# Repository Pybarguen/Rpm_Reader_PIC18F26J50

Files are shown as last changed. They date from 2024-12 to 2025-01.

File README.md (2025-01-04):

# **RPM Reader Using Encoder Sensor and PIC18F26J50**

Photography

**The objetive of this project is to change the speed of a motor using the PWM and read the RPM using a sensor encoder**

Download the files a create a new project on **MPLAB IDE**.

## Materials List

* 1 -PIC18F26J50
* 1- ST7735 128X160 TFT Dispplay
* 1- F249 Speed sensor module
* 1- FF030 DC Motor 3V - 6V
* 1- AMS1117 3.3 Voltaje regulator
* 1- Button N.O
* 1- Mosfet IRF634A
* 1- 2N3904 or 2N2222 Transistor
* 1- PC817 optocoupler
* 1- Pickit2 or recent version
* 2- capacitor 10uF
* 2- 1N4004 diode
* 2- 220 Ohm Resistor
* 3- 10K Ohm Resistor

## **Programs List**
* MPLAB IDE
* Pickit 2 or recent version
* KICAD
* Proteus (Optional)
* Blender

**PIC18F2xJ50** Needs a basic circuit connection for work, you can make a fast circuit on your protoboard using **28-pin SOIC DIP adapter** or you can make the PCB circuit :
**Make sure that you have read the PIC18F2xJ0 this device can be obtain in diferents packages 28-Pin SPDIP/SOIC/SSOP** get the correct adapter for you device

Soic_Adapter

you can get **28-pin SOIC DIP adapter** on this link :

https://www.robotshop.com/es/products/adaptador-sparkfun-soic-a-dip-28-pin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

https://es.aliexpress.com/w/wholesale-SOIC-28-adapter.html?spm=a2g0o.productlist.search.0

## **PIC18F26J50 Lite Develoment Board**

This is a basic PCB board for test faster your prototypes using PIC18F26J50 microcontroller, **you can use it on your protoboard** I'm working in a advance version you could see it in others repositories, you can find lite_version'files on this project.

3DCircuit

**IF You can get this board in PCBWAY**
click here

<a href="https://www.pcbway.com/project/shareproject/PIC16F26J50_Lite_Develoment_Board_c47685f1.html">PCB from PCBWay</a>

**Updating More Information about this setion**

## **Encoder Sensor, DC Motor Bracket and Base**

this parts were built using **Blender** software and **CAD Sketcher Addon**, however you can use any CAD software for read de DXF,OBJ,STL,FBX files.
I used a Laser Machine for cut the parts on MDF 2.5mm WOOD, you can see the parts of the model here and the physical model. **If you can't make this part, you can also use a gear motor and simple basic encoder sensor**

**Technical planes**

Technical Planes

**3D Escene and physical model**

3D Motor Support

## **How to Run**
 If you want to run the code on the microcontroller quickly Download **.Hex** and upload the Program on the microcontroller Using **Pickit Software**, you need to Know the **PIC18F26J50** needs a basic circuit for work, the basic circuit is on the PIC18F26J50 Lite Develoment Board uploaded on this project, if you want some information about this click on this page:
 
 https://www.northernsoftware.com/dev/pic18f/pic18f26j50.htm

PIC18F26J50_BasicCircuit

You can check the circuit using each module for example connect first the **PIC18F26J50** with the **ST7735 TFT Display** and test how to work, then make the same add other module for example **F249 Speed sensor module**

**Connect the circuit using the electronic technical planes on your protoboard**

Full information can be found on the Wiki Setion

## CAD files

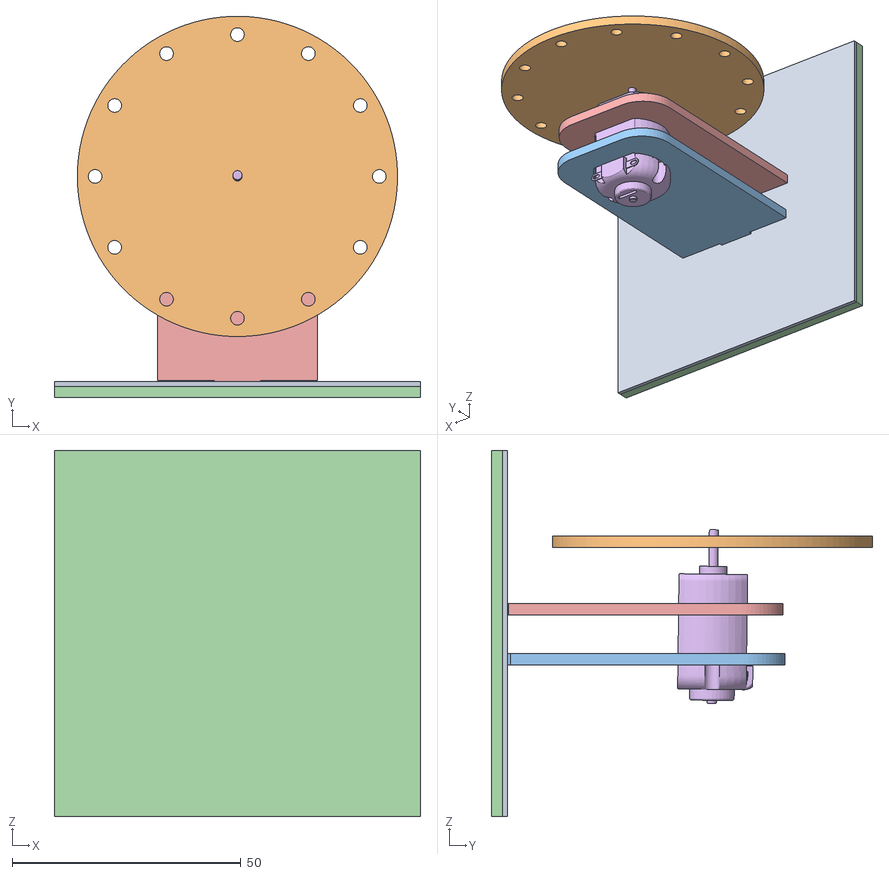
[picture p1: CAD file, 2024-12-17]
TechnicalPlanes/3DMotor_Bracket_Obj.obj
80.0 x 83.4 x 80.0
Base2
Encoder_Sensor
Motor_Bracket2
Base1
Motor_Bracket1
3-6V_DC-Toy-Motor

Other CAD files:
TechnicalPlanes/DcMotor_Bracket_DXF.dxf
TechnicalPlanes/3DMotor_BracketSTL.stl

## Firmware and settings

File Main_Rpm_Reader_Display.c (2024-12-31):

/*
 * File:   Main_Rpm_Reader_Display.c
 * Author: Pybarguen
 *
 * Created on 12 de Diciembre de 2024, 11:21 AM
 */


// CONFIG1L
#pragma config WDTEN = OFF      // Watchdog Timer (Disabled - Controlled by SWDTEN bit)
#pragma config PLLDIV = 2       // PLL Prescaler Selection bits (Divide by 2 (8 MHz oscillator input))
#pragma config STVREN = OFF     // Stack Overflow/Underflow Reset  (Disabled)
#pragma config XINST = OFF      // Extended Instruction Set (Disabled)

// CONFIG1H
#pragma config CPUDIV = OSC3_PLL3// CPU System Clock Postscaler (CPU system clock divide by 3)
#pragma config CP0 = OFF        // Code Protect (Program memory is not code-protected)

// CONFIG2L
#pragma config OSC = INTOSCPLL  // Oscillator (INTOSCPLL)
#pragma config T1DIG = OFF      // T1OSCEN Enforcement (Secondary Oscillator clock source may not be selected)
#pragma config LPT1OSC = OFF    // Low-Power Timer1 Oscillator (High-power operation)
#pragma config FCMEN = OFF      // Fail-Safe Clock Monitor (Disabled)
#pragma config IESO = OFF       // Internal External Oscillator Switch Over Mode (Disabled)

// CONFIG2H
#pragma config WDTPS = 1        // Watchdog Postscaler (1:1)

// CONFIG3L
#pragma config DSWDTOSC = INTOSCREF// DSWDT Clock Select (DSWDT uses INTRC)
#pragma config RTCOSC = INTOSCREF// RTCC Clock Select (RTCC uses INTRC)
#pragma config DSBOREN = OFF    // Deep Sleep BOR (Disabled)
#pragma config DSWDTEN = OFF    // Deep Sleep Watchdog Timer (Disabled)
#pragma config DSWDTPS = G2     // Deep Sleep Watchdog Postscaler (1:2,147,483,648 (25.7 days))

// CONFIG3H
#pragma config IOL1WAY = OFF    // IOLOCK One-Way Set Enable bit (The IOLOCK bit (PPSCON<0>) can be set and cleared as needed)
#pragma config MSSP7B_EN = MSK7 // MSSP address masking (7 Bit address masking mode)

// CONFIG4L
#pragma config WPFP = PAGE_15   // Write/Erase Protect Page Start/End Location (Write Protect Program Flash Page 15)
#pragma config WPEND = PAGE_WPFP// Write/Erase Protect Region Select (valid when WPDIS = 0) (Page WPFP<5:0> through Configuration Words erase/write protected)
#pragma config WPCFG = OFF      // Write/Erase Protect Configuration Region (Configuration Words page not erase/write-protected)

// CONFIG4H
#pragma config WPDIS = OFF      // Write Protect Disable bit (WPFP<5:0>/WPEND region ignored)

// #pragma config statements should precede project file includes.
// Use project enums instead of #define for ON and OFF.
//Pins for Display Control
#define CCS LATBbits.LATB2
#define DCs  LATBbits.LATB3
#define RES LATBbits.LATB4

int counter;//Time counter
char character_buffer[];//Buffer to print char in the display
char rpm_value[];//Buffer to print RPM Value in the display

int seconds;//Seconds counter
int value = 0;//Get the TMR0 Value
float rpm_real;

#include <xc.h>
#define _XTAL_FREQ 16000000 //16MHZ
#include <stdio.h>
#include "Fonts.h"
#include "Image.h"//Image's Buffer 
#include "PIC2XJ50_SPI.h"//SPI library
#include "ST7735.h"//Basic ST7735 Library


//TMR1 INTERRUPT
void __interrupt(high_priority) tcInt(void)
{
    if (TMR1IE && TMR1IF) {  // any timer 0 interrupts?
           
        value = TMR0;//Get the value of TIMER 0 every TMR1 Interrupt
        //YOU CAN TO MODIFY THE INTERUPT TIME USING TMR1 REGISTERS
                     
          counter++;
          //Every 7462 Interrups is one second in the CPU
          //Every second you need to get the value of the TMR0 Using the Encoder Sensor
                  if(counter>=7462)
                  {  
                      counter = 0;
                      seconds = seconds+1;
                      rpm_real = (value/12)*60;                      
                      TMR0 = 0;
                      value = 0;
                  }
          
          //After three second the PWM works and the MOTOR is ON          
          if(seconds>=3 && seconds <7)
          {
         TMR2ON = 1;
         CCPR1L = 0b00011111;  
          }
          
         // Increment the duty cycle every 7 seconds
          if(seconds>=7 && seconds <13)
          {
                CCPR1L = 0b01000000;  
          }
          
           if(seconds>=13 && seconds < 20)
          {
                CCPR1L = 0b01100000;  
          }
           if(seconds>=20 && seconds <27 )
          {
                CCPR1L = 0b00111001;  
          }
          
          
          //Turn Off PWM
            if(seconds>=27)
          {
                 CCPR1L = 0b00000000;  
                
                 
          }
           
        
       
          //MOTOR ON
          
          //RESET TIMER 1
          TMR1 = 65000;       
          TMR1IF=0;
       
          
        
           

       
    }
   
    return;
}
  

void main(void) {
    
    OSCTUNEbits.PLLEN = 1;//ON Internal OScilator
     RCONbits.IPEN = 0;//Disable Interrupts vector levels
   
     
     //This code is necesary to SET the input for TMR0 Counter and the output for the PWM
    //Mapping TMR0 Input PIN
    TRISBbits.TRISB6 = 1; 
   INTCON = 0x00;
    EECON2 = 0X55;//Write 0x55 EECON2 COntrol memory sequence register
    EECON2 = 0XAA;//Write 0xAA EECON2 COntrol memory sequence register    
    PPSCONbits.IOLOCK = 0;// I/O lock is not active, pin configurations can be changed
    
    RPINR4 = 12;//SET TMR0 PIN
    RPOR13 = 14;//Set PWM Pin
    EECON2 = 0X55;//Write 0x55 EECON2 COntrol memory sequence register
    EECON2 = 0XAA;//Write 0xAA EECON2 COntrol memory sequence register
    PPSCONbits.IOLOCK = 1;//I/O lock is active, RPORx and RPINRx registers are write-protected
  
    //Comparadores OFF
    CM1CON  = 0x00;
    CM2CON  = 0x00;
    
    //SPI
   Spi_init();//start spi interface
   Spi_mode(CPOL_1_CPHA_0);//SPI mode 0 0 
   Spi_clock_mode(SPI_MASTER_CLOCK_DIV_4);//SPI clock = FOSC/4 
   TRISBbits.TRISB2 = 0;
   TRISBbits.TRISB3 = 0;
   TRISBbits.TRISB4 = 0;
   TRISCbits.TRISC0 = 1;
     
    ANCON0  = 0xFF;//All analog Pins are Digital NOW  
 
     TRISAbits.TRISA0 = 1;
     INTCON = 0b11000000;//Habilitadas todas las interrupciones globales  
    //Interrupts and TMR0 Configuration
   
 
    //Enable ST7735 TFT DISPLAY
    __delay_ms(10);
    RES = 1;
    CCS = 1;
    DCs = 0;
    
   //TFT DISPLAY INIT
    ST7735S_Init(ST7735_128_x_160);
    
    
    TRISBbits.TRISB7 = 0;
    
    T0CON =  0b00111000;//TIMeR 0 16 bits
    TMR0L = 0;   
    T0CONbits.TMR0ON = 1;

    T1CON = 00001011;//Se activa el Timer 1, Timer 1 de 16bits, prescaler de 1, fuente de reloj Fosc/4    
    TMR1IF = 0;
    PIE1bits.TMR1IE = 1;//Se activa la interrupcion del TIMER1
    TMR1 = 65000;

    //PWM CONFIGURATION BITS
    TRISCbits.TRISC2 = 0;
    PR2 = 255;     
    T2CON =  0b00000011;    
    CCP1CON = 0b00001100; 
    TCLKCONbits.T3CCP2 = 0; 
    TCLKCONbits.T3CCP1 = 0;
    TCLKCONbits.T1RUN = 0;
    TMR2 = 0;
    
   
 
   
    ST7735S_Fill_display(Background_T);
    ST7735S_Fill_image(Image_array);
      while(1)
    {
     
          
          //"RPM_VALUE" is update in TIMER1 Interrupt
     
     ST7735S_Print_String(Blue_Color, "RPM", 0, 100, 2);
     
     sprintf(rpm_value, "%.2f", rpm_real);    
     ST7735S_Print_String(Blue_Color, rpm_value, 0, 120, 2);
     

       
     ST7735S_Print_String(Blue_Color, "Time ", 0, 140, 2);
     
        sprintf(character_buffer, "%d", seconds);    
     ST7735S_Print_String(Blue_Color, character_buffer, 70, 140, 2);
     
     ST7735S_Print_String(Blue_Color, "(s)", 100, 140, 1);
     
    
     
     

         
    }
}

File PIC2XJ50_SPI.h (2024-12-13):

/* Microchip Technology Inc. and its subsidiaries.  You may use this software 
 * and any derivatives exclusively with Microchip products. 
 * 
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
 * IN NO EVENT WILL MICROCHIP BE LIABLE FOR ANY INDIRECT, SPECIAL, PUNITIVE, 
 * INCIDENTAL OR CONSEQUENTIAL LOSS, DAMAGE, COST OR EXPENSE OF ANY KIND 
 * WHATSOEVER RELATED TO THE SOFTWARE, HOWEVER CAUSED, EVEN IF MICROCHIP HAS 
 * BEEN ADVISED OF THE POSSIBILITY OR THE DAMAGES ARE FORESEEABLE.  TO THE 
 * FULLEST EXTENT ALLOWED BY LAW, MICROCHIP'S TOTAL LIABILITY ON ALL CLAIMS 
 * IN ANY WAY RELATED TO THIS SOFTWARE WILL NOT EXCEED THE AMOUNT OF FEES, IF 
 * ANY, THAT YOU HAVE PAID DIRECTLY TO MICROCHIP FOR THIS SOFTWARE.
 *
 * MICROCHIP PROVIDES THIS SOFTWARE CONDITIONALLY UPON YOUR ACCEPTANCE OF THESE 
 * TERMS. 
 */

/* 
 * File:   
 * Author: Daniel Andres Ibarguen Mosquera
 * Comments:
 * Revision history: 
 */

// This is a guard condition so that contents of this file are not included
// more than once.  
#ifndef XC_HEADER_TEMPLATE_H
#define	XC_HEADER_TEMPLATE_H
#include <xc.h> // include processor files - each processor file is guarded.  

/*SPI modes you can see how the SPI modes work here
 https://en.wikipedia.org/wiki/Serial_Peripheral_Interface*/
enum SPI_MODES{
           CPOL_0_CPHA_0, 
           CPOL_0_CPHA_1,
           CPOL_1_CPHA_0,
           CPOL_1_CPHA_1};
           
 enum Spi_master_clock_modes{
     
     SPI_MASTER_CLOCK_DIV_4,             
     SPI_MASTER_CLOCK_DIV_16,
     SPI_MASTER_CLOCK_DIV_64,
     SPI_MASTER_CLOCK_DI_TMR2_2
             
     
     
     
 };       

           
           
           
void Spi_init()
{
    
    TRISCbits.TRISC7 = 0;//Pin SDO    
    TRISBbits.TRISB5 = 1;//Pin SDI
    TRISBbits.TRISB4 = 0;//Pin SCL
    
    SSPCON1bits.SSPEN = 1;//SPI Enable
}

void Spi_mode(enum SPI_MODES data)
{
    if(data == CPOL_0_CPHA_0)
    {
       
        SSPCON1bits.CKP = 0;
        SSPSTATbits.CKE = 0;
     
    }
    else if(data == CPOL_0_CPHA_1)
    {
        
          SSPCON1bits.CKP = 0;
          SSPSTATbits.CKE = 1;
    }
    else if(data == CPOL_1_CPHA_0)
    {
        
           SSPCON1bits.CKP = 1;
          SSPSTATbits.CKE = 0;
    }
    
    else if(data == CPOL_1_CPHA_1)
    {
        
       SSPCON1bits.CKP = 1;
           SSPSTATbits.CKE = 1;
    }
}

void Spi_clock_mode(enum Spi_master_clock_modes data)

{
    if(data == SPI_MASTER_CLOCK_DIV_4)
    {
        
      SSPM01 = 0;
      SSPM11 = 0;
      SSPM21 = 0;
      SSPM31 = 0;
      
    }
    
      if(data == SPI_MASTER_CLOCK_DIV_16)
    {
        SSPM01 = 1;
      SSPM11 = 0;
      SSPM21 = 0;
      SSPM31 = 0;
    
      
      
    }
    
       if(data == SPI_MASTER_CLOCK_DIV_64)
    {
        
      SSPM01 = 0;
      SSPM11 = 1;
      SSPM21 = 0;
      SSPM31 = 0;
      
      
      
      
    }
    
        if(data == SPI_MASTER_CLOCK_DI_TMR2_2)
    {
        
      SSPM01 = 1;
      SSPM11 = 1;
      SSPM21 = 0;
      SSPM31 = 0;
     
      
      
    }
    
    
}

void write_command(int command)
{
 
     CCS = 0;
    SSPBUF =  command;
    while(SSPSTATbits.BF == 0);
    while(PIR1bits.SSPIF == 0);
    PIR1bits.SSPIF = 0;
     CCS = 1;
  
     
    
    
}

void write_data(int data)
{
   
    
     CCS = 0;
    SSPBUF =  data;
    while(SSPSTATbits.BF == 0);
    while(PIR1bits.SSPIF == 0);
    PIR1bits.SSPIF = 0;
     CCS = 1;
     
    
    
}



#endif	/* XC_HEADER_TEMPLATE_H */

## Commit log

2024-12-16 feat: Start-Motor Function have been added, Image buffer array haven added
2024-12-16 Dosc : Technical information about the project : List of materials, Presentation....
2024-12-17 Docs: add information about the Motor_Bracket and Encoder sensor
2024-12-17 Feat: Add 3D models files and DXF files for cut parts on CNC LaserMAchine
    [3DMotor_BracketSTL.stl, 3DMotor_Bracket_Obj.obj, DcMotor_Bracket_DXF.dxf]
2024-12-20 Feat : Add PCB circuit KICAD file
    [Lite_Board.kicad_pcb]
2024-12-27 Feat : added the electronic scheme of the system
    [RPM_Meter_Circuit.kicad_sch]
2024-12-31 Feat : Updated Schematic Kicad Circuit, Added Function for PWM control.
    [RPM_Meter_Circuit.kicad_sch]
2025-01-04 Docs : added information about the PCB board in PCBWAY
